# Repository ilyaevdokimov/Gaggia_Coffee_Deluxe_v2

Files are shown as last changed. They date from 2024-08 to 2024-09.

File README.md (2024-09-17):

Этот проект содержит документацию, описывающую модификацию кофеварки Gaggia Coffee Deluxe с использованием возможностей, предоставляемых контроллерами семейства ESP32.

Модификация предполагает:
1. Обеспечение контроля температуры зоны нагревателя ("температура бойлера") и зоны пролива ("температура группы")
2. Управление нагревом с учётом этих температур в различных режимах
3. Параллельное управление режимами работы кофеварки аппаратными кнопками и через WEB-интерфейс
4. Отображение значимых параметров работы в WEB-интерфейсе, звуковую и световую индикацию событий
5. Контроль и индикация уровня воды в танкере, предотвращение завоздушивания помпы
6. Возможность взвешивания закладки и получения текущего веса напитка
7. Возможность автоматического завершения пролива при достижении целевого веса напитка
8. Подсчёт и индикацию времени пролива
9. Управление параметрами кофеварки и подключением к WiFi-сетям, возможность программного и аппаратного сброса параметров
10. Реализацию бустера пара (усиленный нагрев и подкачка микрообъёмов воды при открытии крана стимера в режиме пара)
11. Возможность определения "боевого" (с закладкой) пролива по показаниям расходомера
12. Сброс давления в бойлере (или в группе, при наличии группы с трёхходовым клапаном) после боевого пролива
13. Автоматическое отключение нагрева по таймауту

Проект ориентирован на максимально сохранение целостности внешнего вида исходного устройства с минимальным вмешательством в его гидравлическую схему и может быть применён практически к любому подобному устройству с минимальными переделками.

Контроль давления в рамках данного проекта не осуществляется в связи с невозможностью прямого измерения этого параметра у кофеварок с редукционным клапаном в зоне пролива.

В качестве управляющей используется плата (клон) WEMOS Lolin S2 Mini с контроллером Esp32 S2, может быть заменена на любой поддерживаемый фреймворком Arduino контроллер семейства Esp32 с достаточным количеством свободных пинов.

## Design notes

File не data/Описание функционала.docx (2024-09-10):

# Кофеварка обеспечивает выполнение следующих функций

- Реализация возможности управления через WEB-интерфейс
- Управление режимами работы с помощью аппаратных и/или программных кнопок
- Настройка параметров, сохраняемых во флеш-памяти кофеварки
- Аппаратный и программный сброс параметров кофеварки
- Измерение и отображение температуры в зоне нагрева и в зоне, максимально близкой к месту пролива
- Управление нагревателем с целью поддержания рабочей температуры группы и бойлера в различных режимах
- Автоматическое отключение нагрева по истечении таймаута
- Бустер пара (постоянный нагрев и циклическая подкачка микрообъёмов воды в бойлер при включённом режиме пара и открытом кране пара)
- Определение и отображение уровня воды в танкере, сигнализация о недостаточном её уровне, предотвращение завоздушивания входной магистрали помпы
- Подсветка рабочей зоны и танкера в зависимости от событий и состояний
- Звуковая сигнализация событий и состояний
- Тарирование и взвешивание закладки
- Измерение и отображение веса напитка во время пролива
- Измерение и отображение времени пролива
- Автоматический пролив до достижения веса напитка, определённого соответствующим параметром или массой закладки
- Измерение и отображение расхода воды при проливе, определение на его основе режима пролива (холостой или боевой)
- Настраиваемый автоматический сброс давления в бойлере или группе (в зависимости от конкретной реализации клапана) по окончании боевого пролива
- Подключение к существующей WiFi-сети
- Создание собственной точки доступа (AP) и реализация Captive Portal для автоматического запуска стартовой страницы
- Диагностика работоспособности исполнительных устройств
- Обновление прошивки по воздуху и через расширитель порта (в т.ч. в режиме «принудительной» прошивки)

## Режимы работы устройства

#### «Ожидание»

Все кнопки управления - экранные и аппаратные, а также помпа - отключены. Если включён нагрев, достигается и поддерживается температура приготовления эспрессо (определяется параметром «Температура бойлера для эспрессо» в Настройках)

#### «Пролив»

Нажата аппаратная или/и экранная кнопка пролива, работает помпа. Если величина расхода воды позволяет определить, что пролив боевой, и определён параметр «Пролив до достижения веса» (либо на странице подготовки к работе был установлен переключатель «Автопролив до ХХХ г»), при достижении установленного веса происходит автоматический переход в режим «Ожидание»

#### «Пар»

Нажата аппаратная или/и экранная кнопка пара. Если включен нагрев, достигается и поддерживается температура парообразования (определяется параметром «Температура бойлера для пара» в Настройках)

#### «Кран»

Паровой кран открыт до срабатывания концевого датчика

#### «Бустер»

Одновременно нажата аппаратная или/и экранная кнопка пара и паровой кран открыт до срабатывания концевого датчика. Если включен нагрев, достигается и поддерживается повышенная на 10°C температура парообразования. Через 10 секунд после активации режима начинается циклическая подкачка небольших объёмов воды для компенсации испарения. Используется для длительного создания мощного пара при взбивании молока

#### «Дренаж»

Одновременно нажата аппаратная или/и экранная кнопка пролива и паровой кран открыт до срабатывания концевого датчика. Используется для охлаждения группы и бойлера после работы в режиме «Пар» или «Бустер», а также при заполнении гидросистемы устройства водой

#### «Диагностика»

Позволяет проверить работоспособность исполнительных устройств (помпы, клапана сброса давления, динамика, нагревателя, подсветки танкера и рабочей зоны)

## WEB-интерфейс

WEB-интерфейс обеспечивает управление кофеваркой, отображение информации о режиме её работы и настройку параметров.

WEB-интерфейс реализован в виде 4 страниц:

- Подготовка к работе
- Панель управления
- Настройки
- Диагностика

### Подготовка к работе

Является стартовой страницей, автоматически отображаемой браузером мобильного устройства с помощью технологии Captive Portal при подключении к точке доступа кофеварки. Также доступна по адресу http://xxx.xxx.xxx.xxx, где xxx.xxx.xxx.xxx – IP адрес собственной точки доступа кофеварки (обычно 192.168.4.1) или IP адрес устройства в сети WiFi (отображается в списке WiFi-сетей на странице Настроек в случае, если кофеварка в данный момент подключена к данной сети).

Предполагает совершение подготовительных действий для приготовления напитка: взвешивания закладки и (опционально) установки целевого веса для автоматического окончания пролива.

Кнопка «Тара» позволяет сбросить текущие показания встроенных весов.

Поле «Закладка» отображает текущий вес на весах. Поле «Вес напитка при BR = 2» автоматически определяет целевой вес напитка исходя из того, что коэффициент экстракции (отношение массы напитка к массе закладки, Brew Ratio, BR) равен классической величине «2».

Кнопка «Автопролив до ХХ.Х г» позволяет запрограммировать автоматическое окончание боевого пролива при достижении целевого веса за вычетом упреждающего веса, учитывающего «докапывание» после выключения пролива (зависит от реализации клапана сброса давления, может быть изменён на странице настройки параметров).

Кнопки в нижней части страницы позволяют перейти к Панели управления и Настройкам.

### Панель управления

Основная страница для работы с устройством. При переходе на неё автоматически включается нагрев. Также доступна по адресу http://xxx.xxx.xxx.xxx/cpSSE.html, где xxx.xxx.xxx.xxx – IP адрес собственной точки доступа кофеварки (обычно 192.168.4.1) или IP адрес устройства в сети WiFi (отображается в списке WiFi-сетей на странице Настроек в случае, если кофеварка в данный момент подключена к данной сети).

Поле «Бойлер/Группа,°C» отображает информацию о температуре в точке нагрева («Температура бойлера», используется ПИД-регулятором для управления нагревателем) и в зоне, максимально близкой к месту пролива («Температура группы», даёт представление о возможности проведения качественной экстракции).

Поле «Режим» отображает текущее состояние кофеварки.

Поле «Вес, г / Время, с» отображает текущий вес приготовляемого напитка (автоматически обнуляется при начале пролива) и время пролива.

Экранные кнопки «Пролив» и «Пар» позволяют управлять режимом работы кофеварки.

Кнопка «Тара» позволяет выполнить принудительное обнуление текущего веса напитка.

Кнопка «Стоп» отключает нагрев и отправляет пользователя на страницу подготовки к работе.

Кнопка «Настройки» позволяет перейти на страницу Настройки параметров.

### Настройки

Позволяет управлять параметрами, влияющими на работу кофеварки. Также доступна по адресу http://xxx.xxx.xxx.xxx/stngsSSE.html, где xxx.xxx.xxx.xxx – IP адрес собственной точки доступа кофеварки (обычно 192.168.4.1) или IP адрес устройства в сети WiFi (отображается в списке WiFi-сетей на странице Настроек в случае, если кофеварка в данный момент подключена к данной сети).

#### Описание параметров:

«Автоматически начинать нагрев при включении» - при установке переключателя нагрев включается автоматически при включении кофеварки, а не только при переходе на страницу Панели управления.

«Температура бойлера для эспрессо» - определяет температуру в зоне нагрева, используемую в качестве целевой ПИД-регулятором при нагреве и поддержании температуры в режиме приготовления эспрессо. Следует понимать, что эта температура не равна температуре пролива, она всегда несколько выше неё, и косвенно на неё влияет.

«Пролив до достижения веса» - установка значения параметра в диапазоне 18…60 г позволяет автоматически останавливать боевой пролив при достижении на весах установленной величины за вычетом упреждающего веса, учитывающего «докапывание» после выключения пролива (см. параметр «Упреждающий вес»). При установке переключателя «Автопролив до ХХ.Х г» на странице подготовки параметр игнорируется.

«Упреждающий вес» - параметр для заблаговременного отключения автоматического пролива. Позволяет учесть «докапывание» при различной реализации клапана сброса давления. В общем случае рекомендуется значение около 5 грамм, если клапан сбрасывает давление в бойлере, и порядка 1-2 грамм, если клапан сбрасывает давление в группе.

«Температура бойлера для пара» - определяет температуру в зоне нагрева, используемую в качестве целевой при нагреве и поддержании температуры в режиме приготовления Пара или Бустера.

«Продолжительность сброса давления» - время открытия клапана сброса давления в бойлере. Увеличение значения может отрицательно влиять на качество парообразования при последующем переходе в режим пара.

«Таймаут авто-отключения нагрева» - время бездействия, по истечении которого будет автоматически отключён нагрев и приглушено освещение.

«Имя точки доступа» - SSID точки доступа, создаваемой кофеваркой.

«Пароль точки доступа» - пароль для подключения к точке доступа, создаваемой кофеваркой.

«Подключение к сетям» - создание, редактирование и удаление пар значений «SSID» - «пароль» для подключения кофеварки к существующим WiFi-сетям.

Кнопка «OK» применяет сделанные настройки и возвращает пользователя на исходную страницу.

Кнопка «Отмена» отменяет сделанные настройки (кроме настроек списка Wi-Fi сетей, которые применяются сразу) и возвращает пользователя на исходную страницу.

Кнопка «Диагностика» под спойлером в верхней части страницы позволяет перейти на страницу диагностики.

### Диагностика

Страница также доступна по адресу http://xxx.xxx.xxx.xxx/check.html, где xxx.xxx.xxx.xxx – IP адрес собственной точки доступа кофеварки (обычно 192.168.4.1) или IP адрес устройства в сети WiFi (отображается в списке WiFi-сетей на странице Настроек в случае, если кофеварка в данный момент подключена к данной сети).

Переключатели «Помпа», «Динамик», «Свет танкера», «Клапан», «Нагрев» и «Свет группы» позволяют включать/отключать соответствующие исполнительные устройства.

Кнопка «Стоп» отключает нагрев и отправляет пользователя на страницу подготовки к работе.

Кнопка «Старт» включает нагрев и отправляет пользователя на страницу панели управления.

## Значения параметров по умолчанию

- Автоматически начинать нагрев при включении: ВЫКЛ.
- Температура бойлера для эспрессо: 113
- Температура бойлера для пара: 135
- Пролив до достижения веса: 0
- Упреждающий вес: 5
- Продолжительность сброса давления: 4
- Таймаут авто-отключения нагрева: 30
- Имя точки доступа: CoffeeAP
- Пароль точки доступа: Up2DownAP
- Подключение к сетям: Пустой список

## Программный сброс параметров

Для выполнения процедуры сброса параметров на значения по умолчанию нажмите кнопку «Сброс» под спойлером на странице Настроек. Появится запрос на подтверждение. В случае согласия произойдёт сброс параметров на значения по умолчанию с последующей перезагрузкой устройства.

## Аппаратный сброс параметров

Если в результате настройки параметров пользователь утратит возможность удалённого взаимодействия с кофеваркой, можно выполнить процедуру «жёсткого» (аппаратного) сброса параметров.

Для выполнения процедуры аппаратного сброса необходимо:

- Выключить кофеварку
- Не включая питания, включить аппаратные кнопки «Пролив» и «Пар»
- Включить питание кофеварки. Устройство загрузится в режиме сброса параметров, о чём будет свидетельствовать длинный гудок и периодическое мигание освещения рабочего стола
- Нажать и удерживать не менее 5 секунд микро-кнопку на тыльной части устройства
- Воспроизведение короткого звукового сигнала и прекращение мигания освещения означает успешный сброс параметров. Микро-кнопку можно отпустить
- Выключить кнопки «Пролив» и «Пар», затем выключить и снова включить питание кофеварки. Произойдёт загрузка устройства со значениями параметров по умолчанию

## Алгоритм работы нагревателя

Для управления нагревателем используется отдельная задача RTOS, реализующая следующие состояния:

- Отсутствие нагрева
- Режим достижения и поддержания температуры эспрессо
- Режим достижения и поддержания температуры пара
- Бустер пара

### Отсутствие нагрева

Флаг необходимости нагрева сброшен, реле отключено, программный ПИД-регулятор остановлен.

### Режим эспрессо

Режим переключения определяется программным ПИД-регулятором исходя из текущей температуры в зоне нагрева («температура бойлера») и уставки, величина которой, в свою очередь, зависит от температуры в зоне пролива («температура группы»):

Температура группы, °C | Уставка ПИД-регулятора, °C
< 80 | Температура бойлера для эспрессо + 3
81 … 85 | Температура бойлера для эспрессо
86 … 93 | Температура бойлера для эспрессо – 3
> 93 | 98

Такой алгоритм позволяет плавно, без «перелётов» выйти на рабочий режим и поддерживать температуру в заданном диапазоне. «Магическое число» 98 при этом не позволяет перегреть группу, хотя некоторое пользователи могут счесть себя обделёнными в части свободы экспериментов.

При начале пролива алгоритм работы нагревателя изменяется: ПИД-регулятор останавливается, а вместо него переключение происходит в режиме «ВКЛ-ВЫКЛ» в зависимости от результата сравнения температуры группы с «магическим числом» 95.

Фактически в этом случае через несколько секунд после начала пролива включается постоянный нагрев, что позволяет компенсировать теплопотери от поступающей из танкера холодной воды, т.е. достижение термостабильности при проливе обеспечивается за счёт высокой энерговооружённости бойлера (отношения объёма бойлера к мощности нагревателя), а не за счёт тепловой инерционности, как в кофеварках с большим объёмом бойлера.

### Режим пара

ПИД-регулятор отключен, переключение происходит в режиме «ВКЛ-ВЫКЛ» в зависимости от результата сравнения температуры бойлера с величиной параметра «Температура бойлера для пара».

### Бустер пара

ПИД-регулятор отключен, переключение происходит в режиме «ВКЛ-ВЫКЛ» в зависимости от результата сравнения температуры бойлера с величиной «10 + значение параметра «Температура бойлера для пара».

Параллельно в этой же задаче реализовано отсроченное на 10 секунд периодическое кратковременное включение помпы для компенсации испарения воды в бойлере.

## Алгоритм работы устройства контроля уровня воды в танкере

Для измерения применяется лазерный дальномер малого радиуса действия, измеряющий расстояние до плоского поплавка на поверхности воды. Полученное расстояние в миллиметрах усредняется методом скользящего среднего с величиной выборки 16.

Далее полученный результат вычитается из 130 («магическое число», полученное эмпирическим путём), что даёт величину, близкую к проценту заполнения танкера. Отрицательные величины при этом приравниваются к 0, величины больше 100 – к 100. Полученное значение выводится в WEB-интерфейс и используется для реализации алгоритма сигнализации о недостаточном уровне воды и предотвращения завоздушивания входной магистрали помпы:

- Если уровень воды в режиме Ожидания меньше или равен 10, переход в режим Пролива становится невозможен
- Если в режиме Пролива уровень воды становится равен 0, пролив останавливается

В обоих случаях срабатывает звуковая и световая сигнализация, предупреждая пользователя о необходимости пополнения запаса воды.

Следует учитывать, что нулевая величина уровня воды не означает полного отсутствия воды в танкере. Число «130» подобрано с таким расчётом, чтобы при «нулевом» уровне в танкере оставалось ещё как минимум 150 мл воды.

## Обновление прошивки

Прошивку устройства и содержимое файлового раздела можно обновлять как удалённо (при наличии Wi-Fi-соединения), так и с использованием проводного соединения с использованием гнезда USB Type C на задней панели устройства.

### Обновление по воздуху

Для выполнения процедуры обновления по воздуху нужно зайти на страницу по адресу http://xxx.xxx.xxx.xxx/update, где xxx.xxx.xxx.xxx – IP адрес собственной точки доступа кофеварки (обычно 192.168.4.1) или IP адрес устройства в сети WiFi (отображается в списке WiFi-сетей на странице Настроек в случае, если кофеварка в данный момент подключена к данной сети).

На странице обновления нужно выбрать тип обновления («OTA Mode»): прошивка («Firmware») или содержимое файлового раздела («LittleFS/SPIFFS»), и затем нажать кнопку выбора файла прошивки для указания на соответствующий файл. После выбора файла загрузка начнётся автоматически. По окончании загрузки устройство автоматически перезагрузится.

### Проводное обновление

Обновление производится обычным для среды Arduino способом при работе с конкретной платой. Соединение нужно производить с полностью выключенной кофеваркой.

В случае, если устройство по каким-либо причинам не может соединиться с компьютером (например, в результате циклической перезагрузки из-за некорректной инициализации и т.п.), можно ввести контроллер платы в режим принудительной загрузки (Boot Mode). Для этого нужно вынуть USB-кабель из устройства, зажать микро-кнопку на задней панели и снова вставить кабель. Плата устройства перейдёт в режим Boot Mode.

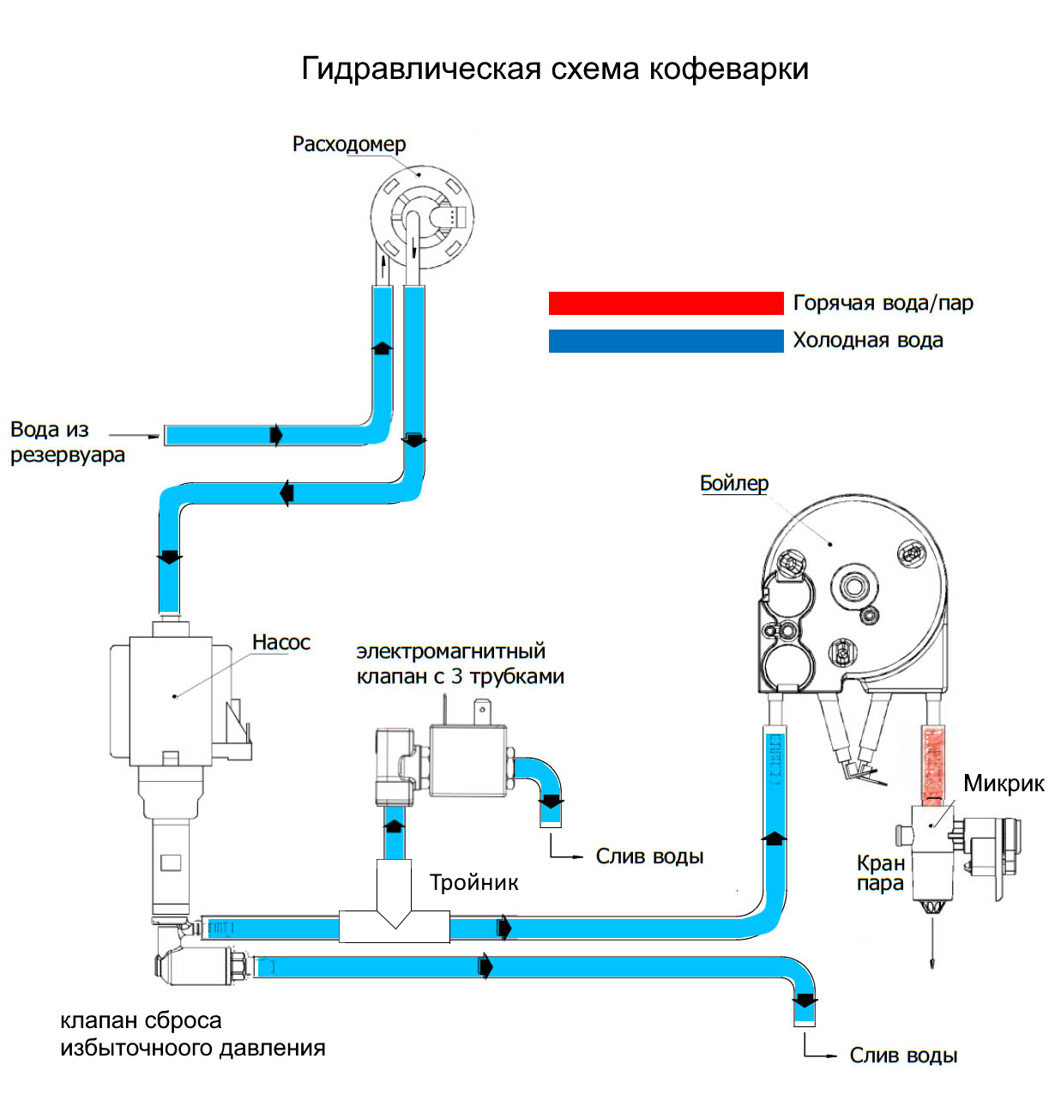
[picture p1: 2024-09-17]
не data/Гидравлическая схема.png

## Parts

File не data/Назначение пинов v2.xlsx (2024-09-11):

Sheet: BOM
 | Список материалов и оборудования |  | Итого | 4741
№ п.п. | Наименование | Количество | Цена | Сумма | Ссылка
1 | Блок питания 24В для питания клапана и подсветки | 1 | 448 | 448 | https://aliexpress.ru/item/1005002568593455.html?pdp_trigger_item_id=0_1005006076665043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
2 | Конвертер напряжения 3.3В для питания остальных устройств | 1 | 39 | 39 | https://aliexpress.ru/item/1005003880321464.html?sku_id=12000027378388707
3 | Соленоидный клапан трёхходовой 24В | 1 | 350 | 350 | https://aliexpress.ru/item/1005004516254556.html?spm=a2g2w.orderdetail.0.0.32a34aa6dttSb3
4 | Плата микроконтроллера ESP32S2 Mini | 1 | 157 | 157 | https://aliexpress.ru/item/1005004609106349.html?sku_id=12000033128298270
5 | Тонкоплёночный NTC-термистор 10 кОм B3435 | 1 | 16 | 16 | https://aliexpress.ru/item/1005003207449474.html?sku_id=12000024663683816
6 | Твердотельное реле переменного тока 5А | 1 | 51 | 51 | https://aliexpress.ru/item/32847956921.html?sku_id=65194306034
7 | Твердотельное реле переменного тока 40А | 1 | 290 | 290 | https://aliexpress.ru/item/4000899938277.html?sku_id=12000025206149674
8 | Флоуметр | 1 | 257 | 257 | https://aliexpress.ru/item/32955644293.html?sku_id=66358407776
9 | Модуль ввода аналогового сигнала для NTC-термистора | 1 | 38 | 38 | https://aliexpress.ru/item/1006278719.html?pdp_trigger_item_id=0_1038403831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
10 | Латунный фитинг F прямой 1/8" - 6мм | 1 | 46 | 46 | https://aliexpress.ru/item/32844571597.html?sku_id=12000021817883266
11 | Латунный фитинг M прямой 1/8" - 4мм | 1 | 40 | 40 | https://aliexpress.ru/item/32898929226.html?sku_id=12000023715679783
12 | Латунный фитинг F угловой 1/8" - 6мм | 1 | 63 | 63 | https://aliexpress.ru/item/32898929226.html?sku_id=12000023715679923
13 | Тройник латунный 8 - 6 - 8мм | 1 | 61 | 61 | https://aliexpress.ru/item/4000833395721.html?sku_id=12000021834551390
14 | Силиконовая трубка высокого давления пищевая 5/10 мм | 1 | 601 | 601 | https://aliexpress.ru/item/4000331057801.html?sku_id=10000001357572616
15 | Плата AD-преобразователя и усилителя датчика взвешивания HX711 | 1 | 56 | 56 | https://aliexpress.ru/item/33041823995.html?sku_id=67334086251
16 | Датчик взвешивания (тензорезистор) 750г | 1 | 260 | 260 | https://aliexpress.ru/item/32670225988.html?sku_id=65880068851
17 | Светодиодный модуль 12В 3W (танкер и рабочая зона) | 4 | 41 | 164 | https://aliexpress.ru/item/4001138356652.html?sku_id=10000014777180732
18 | Модуль лазерного дальномера VL6180X | 1 | 121 | 121 | https://aliexpress.ru/item/1005001572022389.html?sku_id=12000016634417892
19 | Аналоговая клавиатура 4 клавиши (аппаратный сброс) | 1 | 52 | 52 | https://aliexpress.ru/item/33031708148.html?sku_id=67354065000
20 | MOSFET-модуль (клапан и две подсветки) | 3 | 38 | 114 | https://aliexpress.ru/item/1005002626970800.html?sku_id=12000021464531085
21 | Шариковый противоходовой клапан 6 мм | 1 | 53 | 53 | https://aliexpress.ru/item/1005004534196709.html?sku_id=12000029505471016
22 | Комплект цветных проводов 40 шт длиной 40 см | 1 | 109 | 109 | https://aliexpress.ru/item/1005004139263108.html?sku_id=12000028160627992
23 | Комплект регулируемых хомутов для шланга 5 шт 6 - 12 мм | 2 | 81 | 162 | https://aliexpress.ru/item/1005001670475787.html?sku_id=12000017058473718
24 | Модуль MAX6675 с термопарой K-типа | 1 | 140 | 140 | https://aliexpress.ru/item/1843127061.html?sku_id=65665652555
25 | Термопара K-типа с концевиком М4 | 1 | 143 | 143 | https://aliexpress.ru/item/1005005004812425.html?sku_id=12000031315511876
26 | Модуль MAX6675 | 1 | 99 | 99 | https://aliexpress.ru/item/1005005980085656.html?sku_id=12000036724582194
27 | Концевой выключатель | 1 | 51 | 51 | https://aliexpress.ru/item/1005006184411443.html?sku_id=12000036177278561
28 | Силиконовая трубка пищевая 3 - 6 мм 1 м | 1 | 102 | 102 | https://aliexpress.ru/item/1005004537819407.html?sku_id=12000029520574898
29 | Модуль активного буззера | 1 | 28 | 28 | https://aliexpress.ru/item/1005004207872450.html?sku_id=12000028382611075
30 | Зажимы для шланга 6 мм пружинные комплект 10 шт | 1 | 75 | 75 | https://aliexpress.ru/item/1005005147672694.html?sku_id=12000031857131047
31 | Удлинительный кабель 0,5 м USB C Type-C 3,1 штекер-гнездо | 1 | 222 | 222 | https://aliexpress.ru/item/1005003439708042.html?sku_id=12000025799728311
32 | 3X40P штырьковый разъем 90 градусов | 1 | 176 | 176 | https://aliexpress.ru/item/1005005381259648.html?sku_id=12000032823541735
33 | Микросхема MC14490PG для аппаратного подавления дребезга | 1 | 157 | 157 | https://aliexpress.ru/item/4000454460472.html?sku_id=10000001855924183

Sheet: Пины
GPIO | Расположение | Провод | Режим | Нога устройства | VCC | GND | Проверка
1 | слева | жёлтый средний с белой и чёрной метками | Вывод | NTC-термистор | 1 | 1
34 | справа | тёмно-серый средний с белой меткой | Вывод | CS термопары группы MAX6675
33 | справа | чёрный средний с белой меткой | Вывод | CS термистора пара PT100 MAX13865
18 | справа | белый средний с чёрной меткой | Вывод | CS термопары бойлера MAX6675
35 | справа | грязно-фиолетовый с белой меткой | Вывод | SDI
36 | справа | зелёный средний с белой меткой | Вывод | SCK (CLK)
37 | справа | синий средний с белой меткой |  | SDO (SO)
15 | справа | фиолетовый длинный |  | Сигнал готовности PT100
38 | справа | тёмно-зелёный длинный |  | Флоуметр | 1 | 1
8 | слева | оранжевый длинный с белой меткой |  | SDA дальномера | 1 | 1
9 | слева | жёлтый длинный с белой меткой |  | SCL дальномера
21 | справа | светло-зелёный средний | Вывод | Реле ТЭНа |  | 1
6 | слева | белый длинный с чёрной меткой в паре с GND | Вывод | Реле помпы |  | 1
10 | слева | жётый средний с чёрной меткой | Вывод | Мосфет клапана | 1 | 1
11 | слева | жёлтый средний | Вывод | Динамик | 1 | 1
14 | слева | фиолетовый средний | Вывод PWM | Мосфет освещения рабочей зоны | 1 | 1
13 | слева | тёмно-серый длинный |  | Весы data | 1 | 1
12 | слева | фиолетовый длинный | Вывод | Весы clock
5 | слева | тёмно-серый длинный с меткой | Вывод | Мосфет подсветки танкера | 1 | 1
3 | слева | светло-серый короткий |  | Кнопка пролива | 1 | 1
2 | слева | чёрный короткий |  | Кнопка пара
4 | слева | белый короткий |  | Кран пара
0 | справа | оранжевый короткий с переходом на красный |  | Режим прошивки |  | 1
3V3 |  | красный |  |  | 9
GND |  | чёрный/коричневый/синий |  |  |  | 12
Итого свободны: 15, 16, 17, 18.
Сброс параметров: включение при нажатых кнопках пролива, пара и открытом кране пара. После сигнала нужно зажать и держать в течение 5+ секунд кнопк сброса сзади. После этого бибкаем и ждём перезагрузки

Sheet: LOLIN S2 Mini Info
Пины S2, дозволенные к использованию |  |  |  | https://www.studiopieters.nl/esp32-s2-pinout/
 |  |  |  | https://www.espressif.com/sites/default/files/documentation/esp32-s2_datasheet_en.pdf
GPIO | Analog Function | RTC GPIO | Comment | https://codeandlife.com/2022/02/25/using-wemos-s2-pico-esp32-s2-serial-arduino/ - Оживление Serial
GPIO0 |  | RTC_GPIO0 | Strapping pin | GPI0, 45, 46 - нужны для загрузки прошивки, встроенного ПО и ресета. После этих процессов могут использоваться как обычно. При загрузке на них нельзя подавать сигнал, отличный от 1
GPIO1 | ADC1_CH0 | RTC_GPIO1 |  | GPIO 0 - 21 могут использоваться как RTC-пины в режиме глубокого сна (например, для пробуждения)
GPIO2 | ADC1_CH1 | RTC_GPIO2 |  | GPIO1-14 могут использоваться как TOUCH
GPIO3 | ADC1_CH2 | RTC_GPIO3 |  | Прерывание можно вешать на любой пин
GPIO4 | ADC1_CH3 | RTC_GPIO4 |  | I2C-пины по-умолчанию: 8 SDA и 9 SCL. Можно сконфигурировать любой пин, всего имеется 2 канала I2C
GPIO5 | ADC1_CH4 | RTC_GPIO5 |  | SPI - аппаратно можно использовать каналы 2 и 3. Рекомендованы пины 34-37. Программно можно конфигурить любой пин
GPIO6 | ADC1_CH5 | RTC_GPIO6 |  | PWM - любой пин, работающий как OUTPUT, может использовать PWM
GPIO7 | ADC1_CH6 | RTC_GPIO7 |  | DAC1 - GPIO25, DAC2 - GPIO17. Разрешение 8 бит
GPIO8 | ADC1_CH7 | RTC_GPIO8 |  | Input-only пин - GPIO46
GPIO9 | ADC1_CH8 | RTC_GPIO9 |  | ADC - разрешение по-умолчанию - 13 бит! При использовании WiFi ADC2 не доступен (GPIO11 - GPIO20). Используем 1 канал (GPIO1 - GPIO10)
GPIO10 | ADC1_CH9 | RTC_GPIO10
GPIO11 | ADC2_CH0 | RTC_GPIO11
GPIO12 | ADC2_CH1 | RTC_GPIO12
GPIO13 | ADC2_CH2 | RTC_GPIO13
GPIO14 | ADC2_CH3 | RTC_GPIO14
GPIO15 | ADC2_CH4 | RTC_GPIO15
GPIO16 | ADC2_CH5 | RTC_GPIO16
GPIO17 | ADC2_CH6 | RTC_GPIO17
GPIO18 | ADC2_CH7 | RTC_GPIO18
GPIO19 | ADC2_CH8 | RTC_GPIO19 | USB_D-
GPIO20 | ADC2_CH9 | RTC_GPIO20 | USB_D+
GPIO21 |  | RTC_GPIO21
GPIO26 |  |  | SPI0/1
GPIO27 |  |  | SPI0/1
GPIO28 |  |  | SPI0/1
GPIO29 |  |  | SPI0/1
GPIO30 |  |  | SPI0/1
GPIO31 |  |  | SPI0/1
GPIO32 |  |  | SPI0/1
GPIO33
GPIO34
GPIO35
GPIO36
GPIO37
GPIO38
GPIO39 |  |  | JTAG
GPIO40 |  |  | JTAG
GPIO41 |  |  | JTAG
GPIO42 |  |  | JTAG
GPIO43
GPIO44
GPIO45 |  |  | Strapping pin
GPIO46 |  |  | GPI；Strapping pin

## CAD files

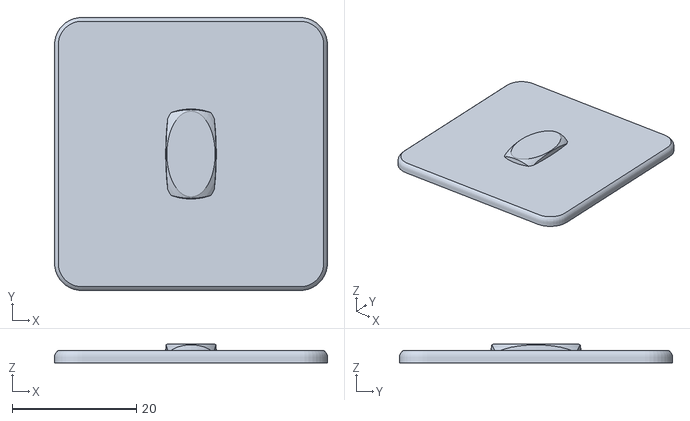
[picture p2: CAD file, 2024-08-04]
не data/STL/GuidePlate.stl
44.0 x 44.0 x 3.00

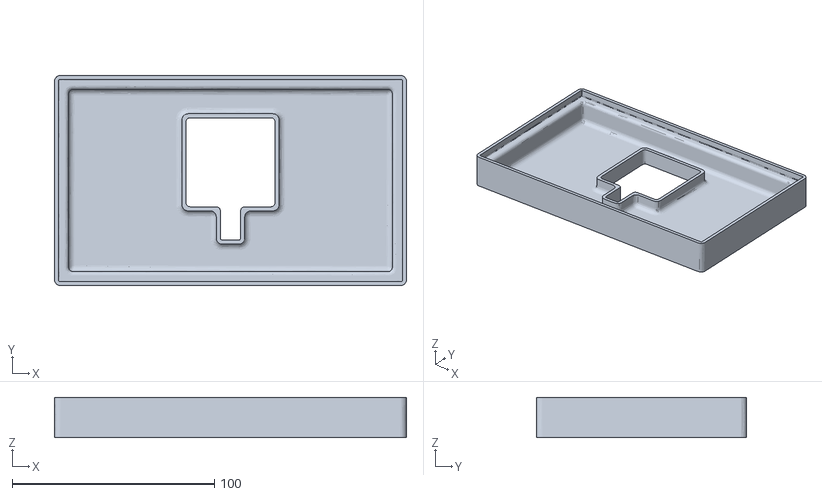
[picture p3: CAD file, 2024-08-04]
не data/STL/DripTrayBottom0.stl
174.0 x 104.0 x 20.0

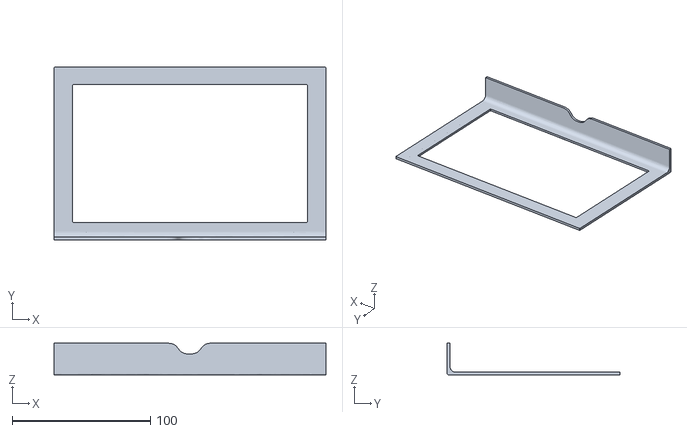
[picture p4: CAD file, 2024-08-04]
не data/STL/DripTrayTop.stl
197.0 x 125.0 x 23.0

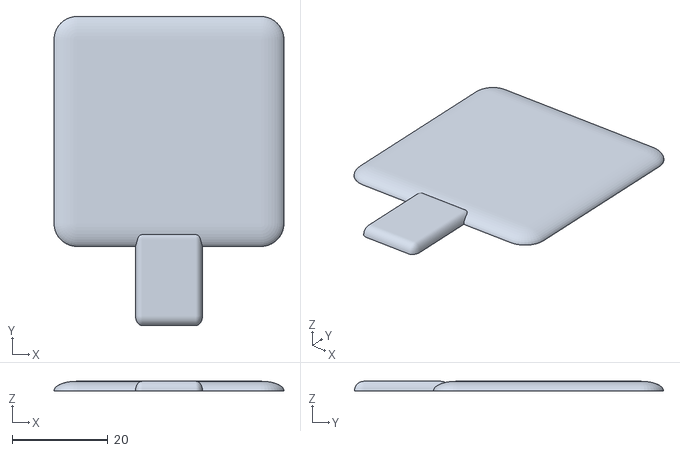
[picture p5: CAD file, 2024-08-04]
не data/STL/Lid.stl
48.0 x 64.5 x 2.00

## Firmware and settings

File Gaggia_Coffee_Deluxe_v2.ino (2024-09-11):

#include <DNSServer.h> // DNS-сервер Espressif
#include <LittleFS.h> // Файловая система Espressif
#include <Preferences.h> // Сервис настроек Espressif
#include <WiFi.h> // Wi-Fi сервисы Espressif
#include <Ticker.h> // Таймер для запуска процедур по интервалу Espressif
#include <ESPAsyncWebServer.h> // WEB-сервисы me-no-dev Me No Dev
#include <ElegantOTA.h>  // Обновление прошивки по воздуху через WEB-интерфейс ayushsharma82 Ayush Sharma
#include <AutoPID.h> // ПИД-регулятор с релейным выходом r-downing Ryan Downing
#include <HX711.h> // Весы Arduino стандартная
#include <GyverMAX6675_SPI.h> // Термопары AlexGyver
#include <Wire.h> // I2C, необходима для работы VL6180X Arduino стандартная
#include <VL6180X.h> // Лазерный дальномер для определения уровня воды в танкере POLOLU
#include <MAX31865_NonBlocking.h> // Неблокирующая библиотека PT100-термистора budulinek
#include "5_Enums.h" // Собственные типы данных. Вынесены в заголовочный файл, чтобы их можно было использовать в качестве параметров и возвращаемых значений функций

#define BOOT_PIN 0 // Кнопка жёсткого сброса и принудительного входа в режим прошивки
#define PASS_BUTTON 3 // Кнопка включения пролива
#define STEAM_BUTTON 2 // Кнопка включения режима пара
#define STEAM_VALVE_BUTTON 4 // Кран пара
#define WORKSPACE_LED 14 // Подсветка рабочей области
#define TANK_LED 5 // Подсветка ёмкости с водой, сигнализирует о достижении целевой температуры режима и критическом уровне воды в баке
#define SOUND_INDICATION 11 // Динамик
#define FLOWMETER 38 // Флоуметр, работает по прерыванию
#define PASS_VALVE 10 // Клапан сброса давления (в бойлере, к сожалению - а надо-то в группе!)
#define SCALES_CLOCK 12 // Весы clock
#define SCALES_DATA 13 // Весы data
#define HEATING 21 // Нагрев
#define PUMP 6 // Помпа
#define BTC_CS_PIN 18 // CS термопары бойлера тип К
#define GTC_CS_PIN 34 // CS термопары группы тип К
#define NTC_PIN 1 // Аналоговый пин NTC-термистора
#define SDI_PIN 35 // SDI
#define CLK_PIN 36 // SCK (CLK)
#define DATA_PIN 37 // SO (SDO)
#define PT100_CS_PIN 33 // PT100-термистор
#define RREF 430.0 // опорное сопротивление PT100-термистора
#define RNOMINAL 100.0 // номинальное сопротивление PT100-термистора

// Настройки по умолчанию
#define ESPRESSO_TEMPERATURE 113 // Целевая температура для эспрессо-пролива 
#define STEAM_TEMPERATURE 135 // Целевая температура парообразования
#define SCALE_CALIBRATION_FACTOR 2404 // Калибровочный коэффициент весов
#define PULSEWIDTH 500 // Интервал обновления ПИД-регулятора
#define PAGE_REFRESH_INTERVAL 300 // Интервал обновления интерфейса
#define PASS_VALVE_LIVE_TRESHOLD 87 // Пороговое значение боевого пролива (время делённое на объём)
#define PASS_VALVE_OPEN_TIME 4 // Время открытия клапана сброса давления в секундах
#define AUTO_OFF_TIMEOUT 30 // Время автоматического отключения при простое (в минутах)
#define PREEMPTIVE_WEIGHT 5 // Разница с Целевой массой, при достижении которой нужно выключать пролив (остальное докапает)
#define BOOSTER_SWAP_INTERVAL 3000 // Интервал включения подкачки микрообъёмов воды в режиме бустера пара
#define BOOSTER_SWAP_TIMEOUT 10000 // Задержка включения подкачки микрообъёмов воды в режиме бустера пара
#define LEDC_TIMER_12_BIT 12 // Используем 12 bit точность для таймера LEDC
#define LEDC_BASE_FREQ 5000 // Используем 5000 Hz в качестве базовой частоты LEDC
#define LEDC_START_DUTY (400) // Начальное заполнение при дыхании
#define LEDC_TARGET_DUTY (4095) // Целевое заполнение при дыхании
#define LEDC_AUTOOFF_DUTY (200) // Заполнение в режиме экономии энергии
#define LEDC_FADE_TIME (2000) // Максимальное время затухания
#define WATER_LEVEL_BUFFER_SIZE 16 // Размер буфера для усреднения показаний дальномера (уровня воды в танкере)
#define SOFT_AP_SSID "CoffeeAP"
#define SOFT_AP_PASSWORD "Up2DownAP"

bool waitingAfterReset = false;
bool isPumpTimeOut = true; // Действует ли задержка включения циклической подкачки для режима бустера пара
uint16_t boosterTimer = 0; // Счётчик задержки включения подкачки в режиме бустера пара
uint16_t boosterSwapTimer = 0; // Счётчик задержки цикла подкачки

// Глобальные переменные, хранящие нативные значения параметров. Позже они сменят свои значения на те, которые записаны в текстовых параметрах:
double setTemp = ESPRESSO_TEMPERATURE; // Температура эспрессо (переменная для ПИД-регулятора). Натив от P1
uint8_t steamTemperature = STEAM_TEMPERATURE; // Температура пара. Натив от P2
uint8_t passValveOpenTime = PASS_VALVE_OPEN_TIME; // Продолжительность открытия клапана сброса давления. Натив от P3
uint8_t autoOffTimeout = AUTO_OFF_TIMEOUT; // Таймаут автоотключения. Натив от P4
bool beginHeatingOnPoweringOn = false; // Начинать ли нагрев сразу при включении кофеварки. Натив от P6
String SoftAP_SSID = SOFT_AP_SSID; // Имя встроенной точки доступа. Натив от P7
String SoftAP_password = SOFT_AP_PASSWORD; // Пароль встроенной точки доступа. Натив от P8
float targetWeight = 0.0; // Целевая масса напитка. При значении 0 не учитывается. Натив от P5
uint8_t preemptiveWeight = 5; // Разница с Целевой массой, при достижении которой нужно выключать пролив (остальное докапает). Натив от P9
float runonceTargetWeight = 0.0; // Целевая масса для разового боевого пролива, переопределяет targetWeight, если находится в допустимых пределах (18...60 г). После срабатывания сбрасывается, не является сохраняемым параметром

// Инициализируем переменные, хранящие текстовые представления параметров, значениями по-умолчанию, зашитыми в прошивке:
String P1 = String(ESPRESSO_TEMPERATURE);
String P2 = String(STEAM_TEMPERATURE);
String P3 = String(PASS_VALVE_OPEN_TIME);
String P4 = String(AUTO_OFF_TIMEOUT);
String P5 = "0";
String P6 = "0";
String P7 = String(SOFT_AP_SSID);
String P8 = String(SOFT_AP_PASSWORD);
String P9 = String(PREEMPTIVE_WEIGHT);
bool isParamterChanges[] = {true, true, true, true, true, true, true, true, true}; // Флаги необходимости обновления. Нам нужно обновить параметры в самое ближайшее время

// Переменные для хранения значений датчиков
double temperature; // Температура бойлера для ПИД-управления
uint16_t rawNTCvalues[WATER_LEVEL_BUFFER_SIZE]; // Массив для усреднения показаний NTC-термистора
uint16_t groupTemperature; // Температура группы по термопаре
uint16_t boilerTemperature = 0; // Температура бойлера по термопаре
float PT100temperature = 0; // Температура в верхней части бойлера по PT100-теристору
float currentWeight = 0; // Текущий вес напитка

uint64_t passBegin; // Отметка времени начала пролива
volatile float passTimeInMillis; // Время пролива в милисекундах. Float для того, чтобы при делении на 1000 сразу получать дробное значение секунд (в прерывании деления нет, только присвоение)
float passTime; // Время пролива в секундах
volatile uint16_t waterStreamValue; // Величина объёма воды, пролитой через группу
uint8_t waterLevel = 100; // Уровень воды в танкере
uint8_t waterLevels[WATER_LEVEL_BUFFER_SIZE]; // Массив для усреднения показаний дальномера (уровнемера)

volatile State currentState = Wait; // Текущее состояние кофеварки. Изначально находмся в состоянии ожидания
volatile State newState = currentState; // Новое состояние, для сравнения с текущим
volatile StateChangeSource stateChangeSource = None; // Индикатор изменения состояния (источник изменения, например кнопка Пролива), по умолчанию изменение состояния отсутствует (None)

// Отладочные переменные
//volatile uint64_t debugValueChangeBegin; // Отметка времени начала отладки значения
//volatile uint64_t debugValueChangedTime; // Время изменения значения

// Флаг для инициализации пинов при первом loop'е, чтобы  иметь возможность засечь bootloop и т.п.
bool runOnce = true;

// Переменные для управления исполнительными устройствами
bool isEspressoHeatingOn = false; // Включен ли нагрев
bool isTemperatureReached = false; // Достигнута ли температура текущего режима

// Переменные для управления "дыханием"
bool isFadeEnded = false; // Статус зажигания/затухания LED (закончилось ли оно)
bool isFadeOn = true; // Переключатель режима затухание/зажигание

Preferences preferences; // Объект настроек
DNSServer dnsServer; // DNS для переадресации запросов Captive Portal
AsyncEventSource events("/events"); // Объект SSE
AsyncWebServer server(80); // Веб-сервер, прослушивающий HTTP-запросы на порту 80
GyverMAX6675_SPI<BTC_CS_PIN> kTCboiler; // Термопара бойлера на аппаратном SPI
GyverMAX6675_SPI<GTC_CS_PIN> kTCgroup; // Термопара группы на аппаратном SPI
MAX31865 rtd(PT100_CS_PIN); // PT100-термистор на аппаратном SPI
VL6180X waterLevelSensor; // Лазерный дальномер на I2C, измеряет уровень воды в танкере
HX711 scale; // Весы

hw_timer_t *autoOFFtimer = NULL; // Таймер автоотключения
bool isAutoOFFneeded = false; // Флаг необходимости выполнения процедуры автоотключения
hw_timer_t *flushTimer = NULL; // Таймер сброса давления
Ticker dataGrabber; // Таймер сбора данных с NTC-термистора для усреднения
uint8_t dataGrabberLoopCounter = 0; // Счётчик для обслуживания буфера значений NTC-термистора, изменяется в пределах 0 ... WATER_LEVEL_BUFFER_SIZE
Ticker controlPanelUpdater; // Таймер обновления данных на странице
uint8_t loopCounter = 0; // Счётчик для обслуживания буфера значений дальномера, изменяется в пределах 0 ... WATER_LEVEL_BUFFER_SIZE

void HeaterControl(void *pvParameters); // Задача управления нагревом

// Обработчики прерываний
void ARDUINO_ISR_ATTR checkButtonStateDueToPass() { // Обработчик прерывания от кнопки пролива (дребезг подавлен аппаратно)
  stateChangeSource = HardPassButton;
}

void ARDUINO_ISR_ATTR checkButtonStateDueToSteam() { // Обработчик прерывания от кнопки Пара (дребезг подавлен аппаратно)
  stateChangeSource = HardSteamButton;
}

void ARDUINO_ISR_ATTR checkButtonStateDueToValve() { // Обработчик прерывания от крана пара (дребезг подавлен аппаратно)
  stateChangeSource = SteamValveButton;
}

void ARDUINO_ISR_ATTR countWaterValue() { // Подпрограмма подсчёта импульсов флоуметра
  if (currentState == Pass) passTimeInMillis = millis() - passBegin;
  waterStreamValue++;
}

void ARDUINO_ISR_ATTR LED_FADE_ISR() { // Обработчик прерывания на достижение максимума/минимума затухания
  isFadeEnded = true;
}

void ARDUINO_ISR_ATTR autoOFF() { // Обработчик прерывания на таймаут простоя
  isAutoOFFneeded = true; // Сигнализируем о необходимости выолнения процедуры автоотключения
}

void ARDUINO_ISR_ATTR closePassValve() { // Обработчик прерывания на таймаут открытия клапана сброса давления
  digitalWrite(PASS_VALVE, LOW); // Закрываем клапан
}

void setup() {
  // Кнопки управления и динамик приходится активировать здесь, поскольку они задействованы при проверке необходимости аппаратного сброса
  delay(1);
  pinMode(PASS_BUTTON, INPUT_PULLUP);
  delay(1);
  pinMode(STEAM_BUTTON, INPUT_PULLUP);
  delay(1);
  pinMode(SOUND_INDICATION, OUTPUT);
  delay(1);
  digitalWrite(SOUND_INDICATION, HIGH); // Утихомириваем динамик
  // Пин 0 загрузку уже отработал, теперь он нам понадобится как индикатор сброса:
  pinMode(BOOT_PIN, INPUT_PULLUP);
  delay(1);

  // Проверяем, не активирован ли режим аппаратного сброса
  if (!digitalRead(PASS_BUTTON) && !digitalRead(STEAM_BUTTON)) { // Кнопки пара и пролива при включении находятся в нажатом состоянии
    pinMode(WORKSPACE_LED, OUTPUT); // Будем сигнализировать подсветкой рабочего стола о ходе сброса параметров
    digitalWrite(WORKSPACE_LED, HIGH);
    uint8_t resetTimer; // Счётчик времени нажатия кнопки принудительного сброса настроек
    bool isHardResetNeeded = true; // Взводим флаг необходимости аппаратного сброса
    // Бибкаем, приглашая нажать кнопку сброса
    digitalWrite(SOUND_INDICATION, LOW);
    delay(1000);
    digitalWrite(SOUND_INDICATION, HIGH);
    delay(1);

    while (isHardResetNeeded) { // Пока флаг необходимости сброса не сброшен
      digitalWrite(WORKSPACE_LED, !digitalRead(WORKSPACE_LED)); // Переключаем подсветку рабочего стола
      delay(1000); // Ждём секунду
      if (!digitalRead(BOOT_PIN)) resetTimer++; // Если кнопка аппаратного сброса нажата, увеличиваем счётчик на время, прошедшее с момента нажатия
      else resetTimer = 0; // в противном случае сбрасываем счётчик
      if (resetTimer >= 5) { // Если кнопка была нажата 5 секунд или более
        doHardReset(); // Делаем аппаратный сброс
        isHardResetNeeded = false; // Выходим из цикла ожидания
      }
    }
    // Сигнализируем включённой подсветкой об удачном сбросе
    digitalWrite(WORKSPACE_LED, HIGH);
    // Дополнительно  сигнализируем об удачном сбросе звуком
    digitalWrite(SOUND_INDICATION, LOW);
    delay(200);
    digitalWrite(SOUND_INDICATION, HIGH);
    delay(1);
    waitingAfterReset = true; // Выставляем флаг невыполнения содержимого loop и отправляемся в вечное ожидание
    return;
  }

  // Запускаем I2C и лазерный дальномер:
  Wire.begin();
  waterLevelSensor.init();
  waterLevelSensor.configureDefault();
  waterLevelSensor.setTimeout(500);

  // Запускаем и калибруем весы:
  scale.begin(SCALES_DATA, SCALES_CLOCK);
  delay(100);
  scale.set_scale(SCALE_CALIBRATION_FACTOR);

  // Таймер автоотключения:
  autoOFFtimer = timerBegin(1000); // Создаём и запускаем аппаратный таймер с разрешением 1Khz
  timerAttachInterrupt(autoOFFtimer, &autoOFF); // Вешаем прерывание на его срабатывание
  timerStop(autoOFFtimer); // Останавливаем, ибо нагрев ещё не включён

  // Таймер сброса давления:
  flushTimer = timerBegin(1000); // Создаём и запускаем аппаратный таймер с разрешением 1Khz
  timerAttachInterrupt(flushTimer, &closePassValve); // Вешаем прерывание на его срабатывание
  timerStop(flushTimer); // Останавливаем. Запустим, когда сделаем боевой пролив
  timerWrite(flushTimer, 0); // Сбрасываем счётчик

  initParams(); // Инициализируем значения текстовых параметров
  updateNativeParameterValues(); // Обновляем значения нативных параметров, сбрасываем таймеры и устанавливаем им время и параметры срабатывания

  // Запускаем файловую систему LittleFS, при неудаче сигнализируем длинным гудком:
  if (!LittleFS.begin()) {
    digitalWrite(SOUND_INDICATION, LOW);
    delay(5000);
    digitalWrite(SOUND_INDICATION, HIGH);
    delay(1);
  }
  else {
    startWiFi(); // Подсоединяемся к Wi-Fi точке доступа и создаем свою точку доступа
    startWEBServer(); // Запускаем HTTP-сервер
  }

  dataGrabber.attach_ms(10, getNTCvalue); // Таймер записи очередного значения NTC-термистора в буфер. Срабатывает каждые 10 мс
  controlPanelUpdater.attach_ms(PAGE_REFRESH_INTERVAL, updateControlPanel); // Таймер процедуры актуализации панели управления (странички) Срабатывает каждые PAGE_REFRESH_INTERVAL мс
  rtd.begin(); // Запускаем объект неблокирующей библиотеки PT100-термистора
}

void loop() {
  if (!waitingAfterReset) { // Выполняем loop только если НЕ находимся в режиме аппаратного сброса
    if (runOnce) { // Одноразовое удовольствие
      analogReadResolution(12); // Без этого почему-то работает 13 битное разрешение...
      pinInitialization(); // Переназначаем режимы GPIO и приводим их в начальное состояние
      xTaskCreate(HeaterControl, "HC", 4096, NULL, 1, NULL); // Создаём и запускаем задачу управления нагревом
      isEspressoHeatingOn = beginHeatingOnPoweringOn; // Включаем (или нет) нагрев при включении кофеварки

      // Сигнализируем об успешной загрузке:
      digitalWrite(SOUND_INDICATION, LOW);
      delay(25);
      digitalWrite(SOUND_INDICATION, HIGH);

      runOnce = false; // Было хорошо, но больше так не надо
    }

    if (stateChangeSource != None) { // Если какой-либо из элементов управления является поводом для изменения состояния...
      if (currentState != checkState()) changeState(); // ...и проверка элементов управления это подтверждает - изменяем состояние...
      stateChangeSource = None; // ...и сбрасывем индикатор необходимости его смены
    }

    ElegantOTA.loop(); // Обновляемся по воздуху
    lightIndication(); // Сигнализируем светом о выходе на режим
  }
}

void pinInitialization() {
  // NTC-термистор
  pinMode(NTC_PIN, INPUT);
  // Кнопки управления. Обязательно нужен INPUT_PULLUP, без этого они не работают!
  attachInterrupt(PASS_BUTTON, checkButtonStateDueToPass, CHANGE); // Кнопка включения пролива
  attachInterrupt(STEAM_BUTTON, checkButtonStateDueToSteam, CHANGE); // Кнопка режима пара
  pinMode(STEAM_VALVE_BUTTON, INPUT_PULLUP);
  attachInterrupt(STEAM_VALVE_BUTTON, checkButtonStateDueToValve, CHANGE); // Кран пара
  // Флоуметр
  pinMode(FLOWMETER, INPUT_PULLUP); // Чтобы ловить сигнал от флоуметра, а не шумы
  attachInterrupt(FLOWMETER, countWaterValue, FALLING); // срабатываем на падение сигнала
  // Нагрев
  pinMode(HEATING, OUTPUT);
  // Помпа
  pinMode(PUMP, OUTPUT);
  // Клапан сброса давления
  pinMode(PASS_VALVE, OUTPUT);
  // LED-подсветка рабочей области
  ledcAttach(WORKSPACE_LED, 5000, 12); // Конфигурируем автоматически выбранный канал и вешаем на него наш MOSFET
  // LED-подсветка ёмкости с водой
  ledcAttach(TANK_LED, 5000, 12); // Конфигурируем автоматически выбранный канал и вешаем на него наш MOSFET
  isFadeEnded = true;
}

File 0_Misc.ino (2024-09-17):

// Подпрограмма выполнения аппаратного сброса
void doHardReset() {
  preferences.begin("gSettings", false); // Открываем настройки на запись
  // Сбрасываем значения текстовых параметров:
  if (preferences.isKey("P1")) preferences.putString("P1", String(ESPRESSO_TEMPERATURE));
  if (preferences.isKey("P2")) preferences.putString("P2", String(STEAM_TEMPERATURE));
  if (preferences.isKey("P3")) preferences.putString("P3", String(PASS_VALVE_OPEN_TIME));
  if (preferences.isKey("P4")) preferences.putString("P4", String(AUTO_OFF_TIMEOUT));
  if (preferences.isKey("P5")) preferences.putString("P5", "0");
  if (preferences.isKey("P6")) preferences.putString("P6", "0");
  if (preferences.isKey("P7")) preferences.putString("P7", String(SOFT_AP_SSID));
  if (preferences.isKey("P8")) preferences.putString("P8", String(SOFT_AP_PASSWORD));
  if (preferences.isKey("P9")) preferences.putString("P9", String(PREEMPTIVE_WEIGHT));
  preferences.end(); // Закрываем настройки
}

// Функция проверки состояния
State checkState() {
  if (currentState == Diagnostics) return Diagnostics; // Если мы в режиме диагностки, то какие бы аппаратные кнопки мы не нажимали, всё равно остаёмся в режиме диагностики
  // Да, это можно написать компактней. Но я считаю, что так лучше читается и легче вносить правки:
  switch (stateChangeSource) {  // Таблица новых состояний в зависимости от старого состояния и источника его изменения
    case HardPassButton:
      if (!digitalRead(PASS_BUTTON)) { // Кнопка Пролива нажата
        if (currentState == Wait) newState = Pass;
        if (currentState == Pass) newState = Pass;
        if (currentState == Steam) newState = Steam;
        if (currentState == SteamValve) newState = Drain;
        if (currentState == Drain) newState = Drain;
        if (currentState == Booster) newState = Booster;
      }
      else { // Кнопка Пролива отжата
        if (currentState == Wait) newState = Wait;
        if (currentState == Pass) newState = Wait;
        if (currentState == Steam) newState = Steam;
        if (currentState == SteamValve) newState = SteamValve;
        if (currentState == Drain) newState = SteamValve;
        if (currentState == Booster) newState = Booster;
      }
      break;
    case HardSteamButton:
      if (!digitalRead(STEAM_BUTTON)) { // Кнопка Пара нажата
        if (currentState == Wait) newState = Steam;
        if (currentState == Pass) newState = Pass;
        if (currentState == Steam) newState = Steam;
        if (currentState == SteamValve) newState = Booster;
        if (currentState == Drain) newState = Drain;
        if (currentState == Booster) newState = Booster;
      }
      else { // Кнопка Пара отжата
        if (currentState == Wait) newState = Wait;
        if (currentState == Pass) newState = Pass;
        if (currentState == Steam) newState = Wait;
        if (currentState == SteamValve) newState = SteamValve;
        if (currentState == Drain) newState = Drain;
        if (currentState == Booster) newState = SteamValve;
      }
      break;
    case SteamValveButton: // Кран Пара...
      delay(10); // Даём крану очувствоваться. Мы не очень-то доверяем сигналам от него, поэтому нужно перепроверять:
      if (!digitalRead(STEAM_VALVE_BUTTON)) { // ...открыт
        if (currentState == Wait) newState = SteamValve;
        if (currentState == Pass) newState = Drain;
        if (currentState == Steam) newState = Booster;
        if (currentState == SteamValve) newState = SteamValve;
        if (currentState == Drain) newState = Drain;
        if (currentState == Booster) newState = Booster;
      }
      else { // ...закрыт
        if (currentState == Wait) newState = Wait;
        if (currentState == Pass) newState = Pass;
        if (currentState == Steam) newState = Steam;
        if (currentState == SteamValve) newState = Wait;
        if (currentState == Drain) newState = Pass;
        if (currentState == Booster) newState = Steam;
      }
      break;
    case SoftPassButtonOn: // Экранная кнопка Пролива нажата
      if (currentState == Wait) newState = Pass;
      if (currentState == Pass) newState = Pass;
      if (currentState == Steam) newState = Steam;
      if (currentState == SteamValve) newState = Drain;
      if (currentState == Drain) newState = Drain;
      if (currentState == Booster) newState = Booster;
      break;
    case SoftPassButtonOff: // Экранная кнопка Пролива отжата
      if (currentState == Wait) newState = Wait;
      if (currentState == Pass) newState = Wait;
      if (currentState == Steam) newState = Steam;
      if (currentState == SteamValve) newState = SteamValve;
      if (currentState == Drain) newState = SteamValve;
      if (currentState == Booster) newState = Booster;
      break;
    case SoftSteamButtonOn: // Экранная кнопка Пара нажата
      if (currentState == Wait) newState = Steam;
      if (currentState == Pass) newState = Pass;
      if (currentState == Steam) newState = Steam;
      if (currentState == SteamValve) newState = Booster;
      if (currentState == Drain) newState = Drain;
      if (currentState == Booster) newState = Booster;
      break;
    case SoftSteamButtonOff: // Экранная кнопка Пара отжата
      if (currentState == Wait) newState = Wait;
      if (currentState == Pass) newState = Pass;
      if (currentState == Steam) newState = Wait;
      if (currentState == SteamValve) newState = SteamValve;
      if (currentState == Drain) newState = Drain;
      if (currentState == Booster) newState = SteamValve;
      break;
    case None: // Не должно такого быть, просто на всякий случай
      newState = currentState;
      break;
    default: // Если что-то пошло не так, переходим в режим Ожидания
      newState = Wait;
      break;
  }
  return newState;
}
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

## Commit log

2024-08-04 Удаление Gaggia_Coffee_Deluxe_v2.ino.esp32s2.bin
2024-08-04 Удаление Проблема с LittleFS.url
2024-08-04 Удаление Уроки по Fusion.url
2024-08-05 Убрал отладочную информацию
2024-08-06 Заменил задачу вывода данных на страницу на процедуру по таймеру
2024-08-06 Быстрые весы + чистка кода
2024-08-06 Дополнил BOM
    [Назначение пинов v2.xlsx]
2024-08-07 Добавил страничку диагностики
2024-08-09 Чистка кода, мелкие исправления
    [0_Misc.ino, 1_WiFi.ino, 3_WEB.ino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]
2024-08-11 Добавил работу экранных кнопок. Но она не совсем корректна
2024-08-26 Новая процедура смены состояния, экранные кнопки работают корректно
    [Назначение пинов v2.xlsx]
2024-09-03 Реализован пролив до целевой массы, добавлена документация
    [Назначение пинов v2.xlsx]
2024-09-10 Исправления и дополнения в документации
    [0_Misc.ino, 4_Tasks.ino, Gaggia_Coffee_Deluxe_v2.ino]
2024-09-10 Create Гидравлическая схема.png
2024-09-11 Подключено измерение температуры PT100-термистором
    [Назначение пинов v2.xlsx]
2024-09-17 Исправления гидравлической схемы
